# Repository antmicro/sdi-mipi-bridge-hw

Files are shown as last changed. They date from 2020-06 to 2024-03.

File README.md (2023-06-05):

# SDI to MIPI CSI-2 Bridge Hardware Design

Copyright (c) 2020-2023 [Antmicro](https://www.antmicro.com)

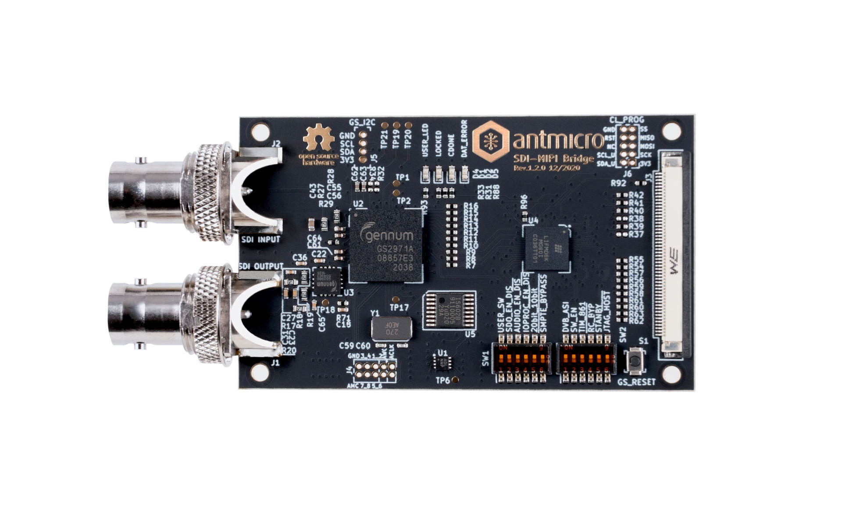
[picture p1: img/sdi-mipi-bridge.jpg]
SDI-MIPI Bridge


## Overview

This project contains open hardware KiCad design files for Antmicro's SDI to MIPI CSI-2 bridge.
This device enables connecting industrial and filmmaking cameras and video accessories to edge AI platforms which often include the MIPI CSI-2 interface.

The board includes an SDI input BNC connector and Antmicro's standard 50-pin FFC output connector (compatible with a range of our open hardware boards) exposing MIPI CSI-2 lanes as well as an I2C bus for configuration.

An additional SDI output (loopback) BNC connector is also available.

SDI signal conversion is implemented with a Semtech [GS2971A](https://www.semtech.com/products/broadcast-video/receivers-deserializers/gs2971a) deserializer which passes the parrallel 10-bit video data to the Lattice CrossLink [LIF-MD6000-6KMG80I](http://www.latticesemi.com/en/Products/FPGAandCPLD/CrossLink).
The CrossLink FPGA includes programmable logic and dedicated MIPI D-PHY transceivers.
It can be configured to accept parallel video data from the deserializer and transmit it over MIPI CSI-2 to the host platform.
SPI and I2C programming interfaces are exposed so the deserializer and the CrossLink FPGA can be configured from the host platform.

### Project structure

The main directory contains KiCad PCB project files, a LICENSE and README.
The remaining files are stored in the following directories:

* ``lib`` - contains the component libraries
* ``doc`` - contains board schematic in PDF
* ``img`` - contains graphics for this README

## Key Features

* Implements Single Link (3G-SDI) video conversion
* Supports SMPTE ST 425 (Level A and Level B), SMPTE ST 424, SMPTE ST 292, SMPTE ST 259-C and DVB-ASI as defined by the Semtec GS2971A specification
* Integrated loopback BNC connector for easy daisy-chaining with multiple SDI video accessories
* Audio de-embedder for 8 channels of 48kHz audio exposed on I2S 10 pin header
* Two 4-lane MIPI CSI-2 interfaces with up to 6 Gbps, each exposed on the 50 pin FFC connector.
* I2C configuration interface to handle CrossLink FPGA and SDI deserializer
* SPI interface for CrossLink configuration
* 12x DIP switches to initially configure the deserializer
* 2 LED indicators for user purposes

## Getting started

Please refer to the [SDI to MIPI CSI-2 bridge](https://github.com/antmicro/sdi-mipi-bridge) repository which aggregates the hardware design (this project), linux kernel sources, how-to documentation and reference HDL design for the CrossLink FPGA.

## License

This project is licensed under the [Apache-2.0](LICENSE) license.

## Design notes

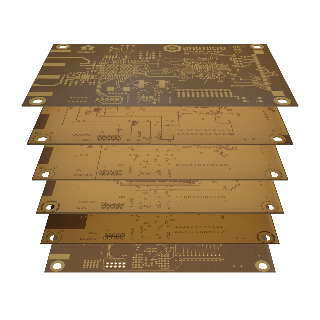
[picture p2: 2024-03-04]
assets/previews/layer1_thumbnail.webp

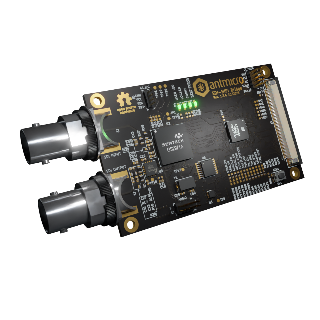
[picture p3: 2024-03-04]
assets/previews/leftT_thumbnail.png

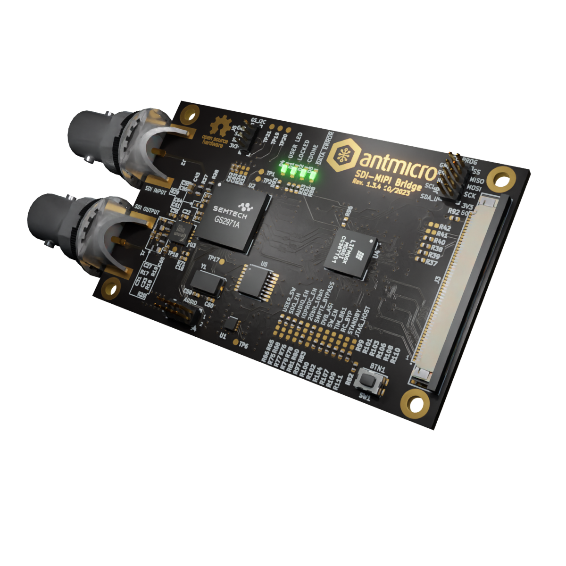
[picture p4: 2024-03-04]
assets/previews/rightT.webp

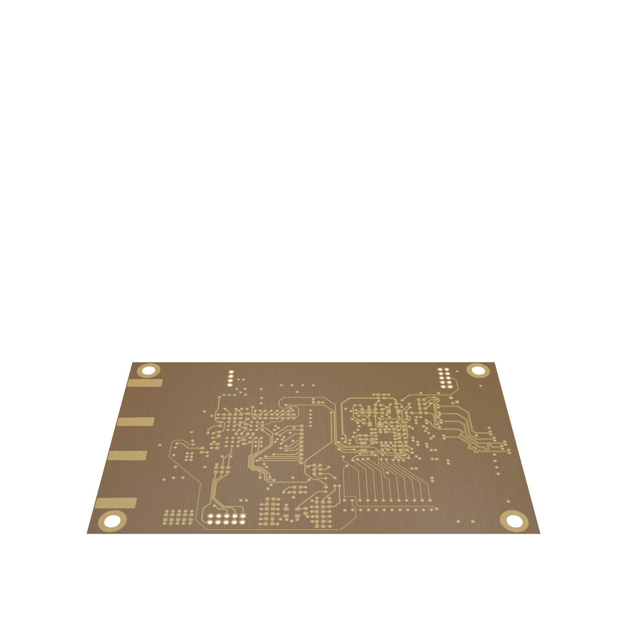
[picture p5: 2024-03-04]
assets/previews/layer6.png

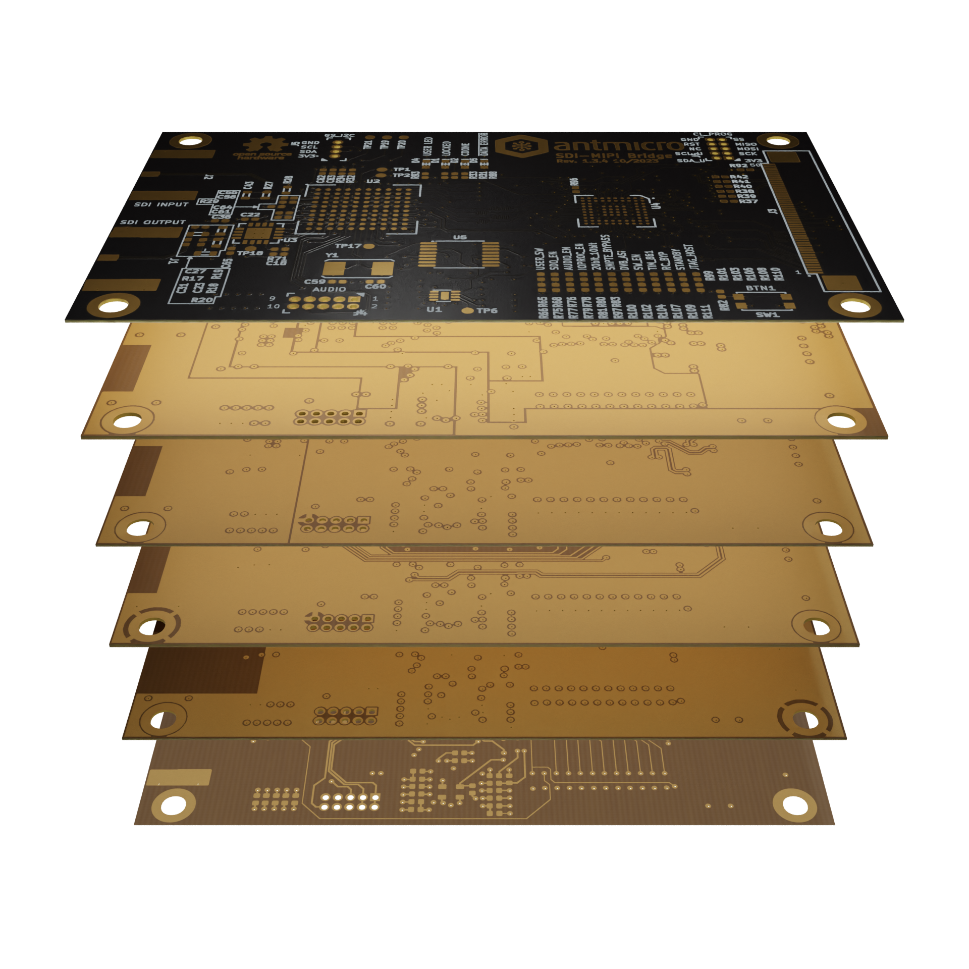
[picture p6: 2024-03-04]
assets/previews/stackup.png

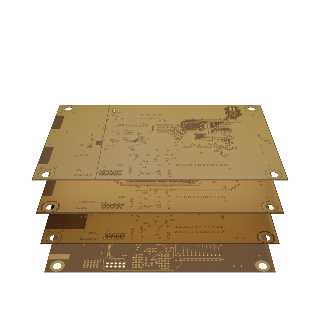
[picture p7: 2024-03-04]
assets/previews/layer3_thumbnail.webp

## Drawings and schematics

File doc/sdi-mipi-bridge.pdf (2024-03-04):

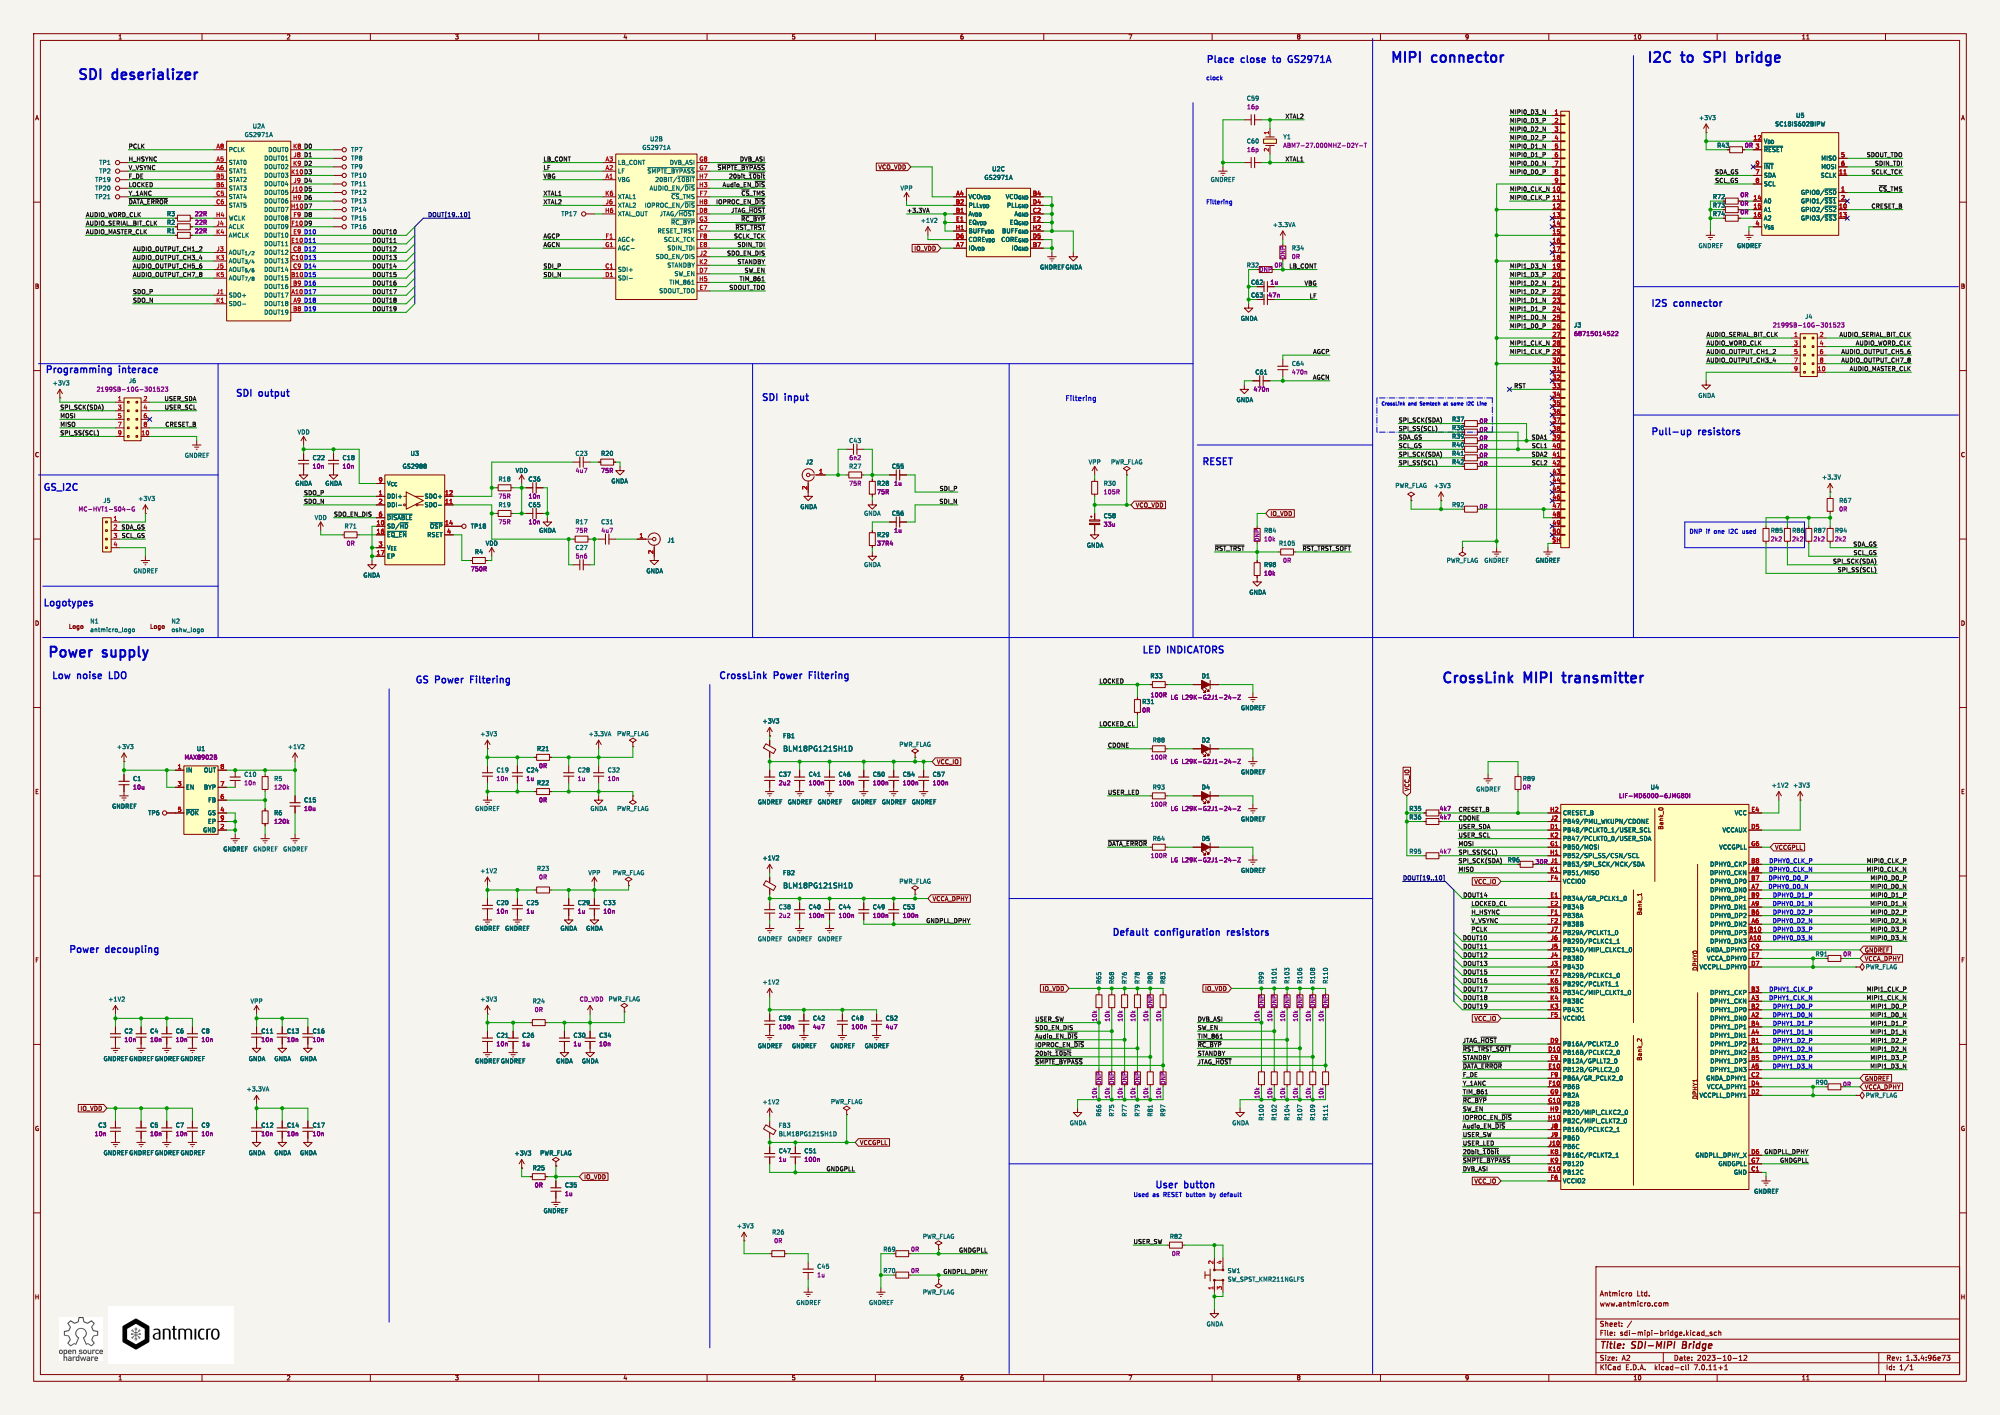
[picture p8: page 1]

clock GS Power Filtering

Used as RESET button by default

Antmicro Ltd.
File: sdi-mipi-bridge.kicad_sch Sheet: / www.antmicro.com

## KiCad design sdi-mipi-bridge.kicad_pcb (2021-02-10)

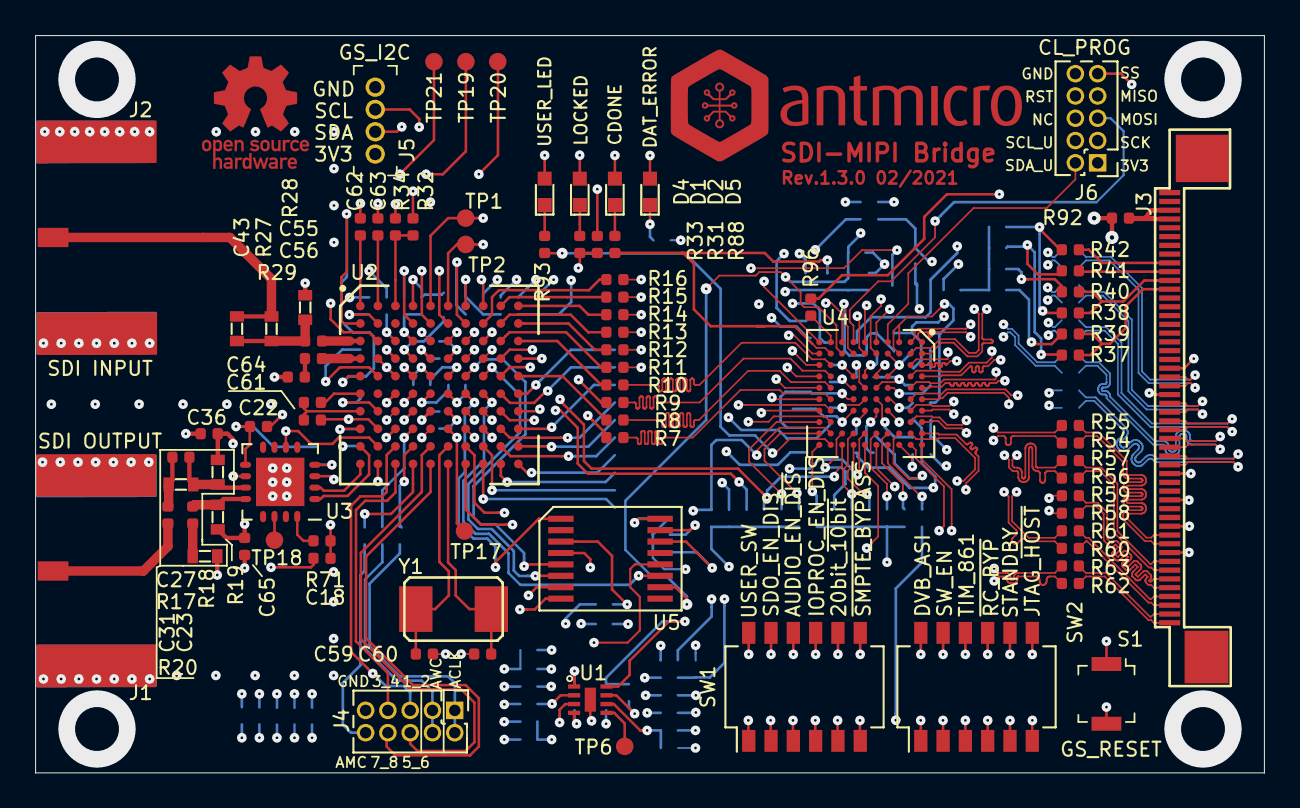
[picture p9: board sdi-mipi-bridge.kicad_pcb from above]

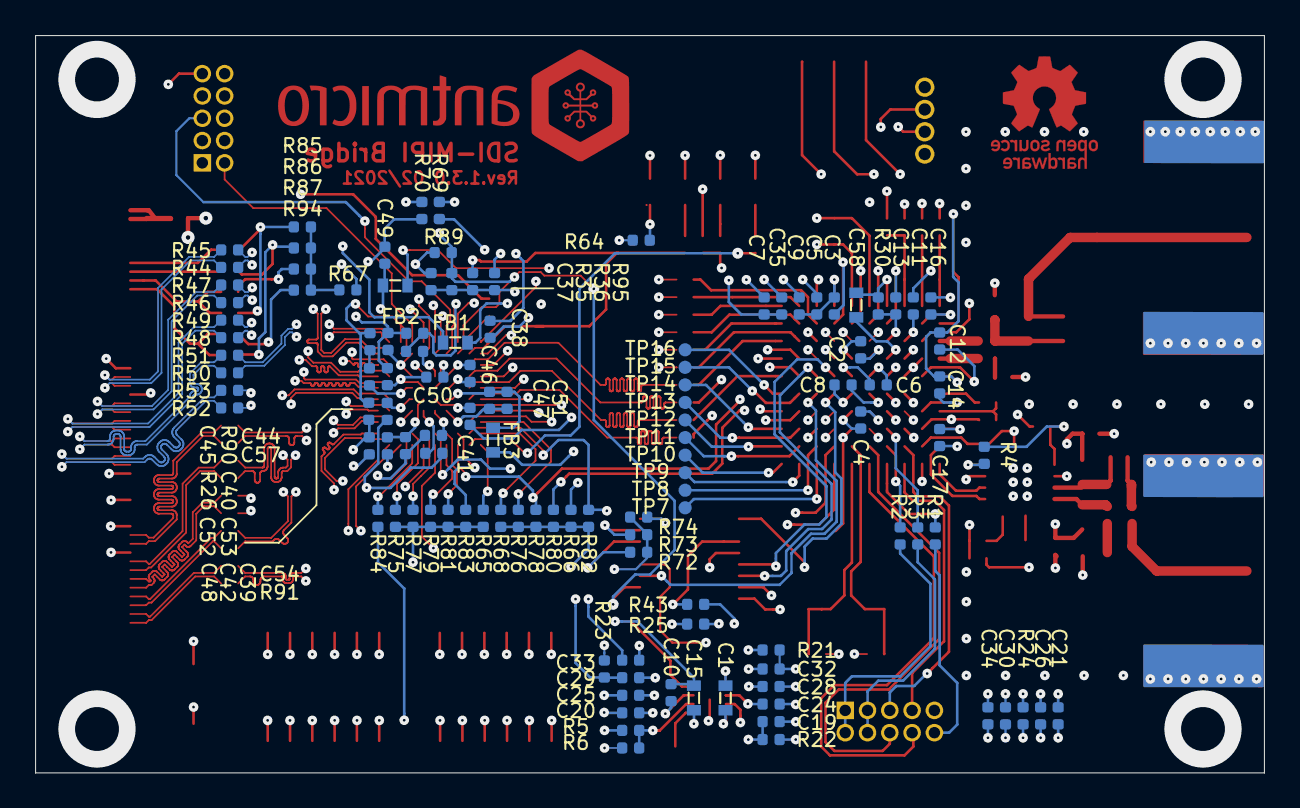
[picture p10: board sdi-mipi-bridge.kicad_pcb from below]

Board: 6 copper layers, 70.0 x 42.0 mm, 203 parts (116 on the bottom side), 174 nets.

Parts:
C1, C15: C_10u_0603; 0603-cap
C2, C3, C4, C5, C6, C7, C8, C9, C10, C11, C12, C13, C14, C16, C17, C18, C19, C20, C21, C22, C32, C33, C34, C36, C65: C_10n_0402; 0402-cap
C23, C31, C42, C52: C_4u7_0402; 0402-cap
C24, C25, C26, C28, C29, C30, C35, C45, C47, C55, C56, C62: C_1u_0402; 0402-cap
C27: C_5n6_0402; 0402-res
C37, C38: C_2u2_0402; 0402-cap
C39, C40, C41, C44, C46, C48, C49, C50, C51, C53, C54, C57: C_100n_0402_6V3; 0402-cap
C43: C_6n2_0603; 0603-res
C58: C_33u_0603; 0603-cap
C59, C60: C_16p_0402; 0402-res
C61, C64: C_470n_0402; 0402-cap
C63: C_47n_0402; 0402-cap
D1, D2, D4, D5: LG_L29K-G2J1-24-Z; LED_0603
FB1, FB2, FB3: BLM18PG121SH1D; 0603-res
J1, J2: 112740-13; BNC_Edge_Conn
J3: WE_68715014522_ONE-SIDE
J4, J6: GRPB052VWVN-RC; PinHeader_2x05_P1.27mm_Vertical
J5: GRPB041VWVN-RC; PinHeader_1x4_P1.27mm_Drill.7mm
N1: antmicro_logo; antmicro-logo_scaled_20mm
N2: oshw_logo; oshw-logo
R1, R2, R3: R_22R_0402; 0402-res
R4: R_750R_0402; 0402-res
R5, R6: R_120k_0402; 0402-res
R7, R8, R9, R10, R11, R12, R13, R14, R15, R16, R21, R22, R23, R24, R25, R26, R31, R32, R34, R37, R38, R39, R40, R41, R42, R43, R44, R45, R46, R47, R48, R49, R50, R51, R52, R53, R54, R55, R56, R57, R58, R59, R60, R61, R62, R63, R67, R69, R70, R71, R72, R73, R74, R89, R90, R91, R92: R_0R_0402; 0402-res
R17, R18, R19, R20, R27, R28: R_75R_0603; 0603-res
R29: R_37R4_0402; 0402-res
R30: R_105R_0402; 0402-res
R33, R64, R88, R93: R_100R_0402; 0402-res
R35, R36, R84, R95: R_4k7_0402; 0402-res
R65, R66, R68, R75, R76, R77, R78, R79, R80, R81, R82, R83: R_10k_0402; 0402-res
R85, R86, R87, R94: R_2k2_0402; 0402-res
R96: R_30R_0402; 0402-res
S1: B3U-1000P; Switch_Tactile_SMD_B3U-1000P
SW1, SW2: SW_DIP_x06; SW_SPST_6_Slide_MCDHN-06F-T-V_P1.27mm
TP1, TP2, TP6, TP17, TP18, TP19, TP20, TP21: TP_SMD1MM; Testpoint_smd_1mm
TP7, TP8, TP9, TP10, TP11, TP12, TP13, TP14, TP15, TP16: TP_SMD_0_75MM; Testpoint_smd_0_75mm
U1: MAX8902B; TDFN2x2
U2: GS2971A; BGA100_11x11mm
U3: GS2988; QFN-16_EP_4x4_Pitch0.65mm
U4: CrossLink_LIF-MD6000-6JMG80I; BGA-80pin_ckfBGA80_7.0x7.0mm
U5: SC18IS602BIPW; SC18IS602B
Y1: ABM7_27.000MH_D2Y_T; ABM7_OSC

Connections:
+1V2: C2.1, C4.1, C6.1, C8.1, C10.1, C15.1, C20.1, C25.1, C39.1, C42.1, C48.1, C52.1, FB2.1, FB3.1, R5.1, R23.1, U1.8, U2.D6, U2.E6, U2.F6, U2.G6, U4.E4, U4.E6
+3.3VA: C12.1, C14.1, C17.1, C28.1, C32.1, R21.2, R34.1, U2.B1, U2.E1, U2.H1
+3V3: C1.1, C19.1, C21.1, C24.1, C26.1, FB1.1, J5.1, J6.1, R21.1, R24.1, R25.1, R26.1, R43.1, R67.1, R92.2, U1.1, U1.3, U4.D5, U5.12
/20bit_~10bit~: R76.2, SW1.8, U2.H7, U4.K8
/AGCN: C61.1, C64.2, U2.G1
/AGCP: C64.1, U2.F1
/AUDIO_MASTER_CLK: J4.10, R1.1
/AUDIO_OUTPUT_CH1_2: J4.5, U2.J3
/AUDIO_OUTPUT_CH3_4: J4.7, U2.K3
/AUDIO_OUTPUT_CH5_6: J4.6, U2.J5
/AUDIO_OUTPUT_CH7_8: J4.8, U2.K5
/AUDIO_SERIAL_BIT_CLK: J4.1, J4.2, R2.1
/AUDIO_WORD_CLK: J4.3, J4.4, R3.1
/Audio_EN_~DIS~: R80.2, SW1.10, U2.H3, U4.J8
/CDONE: R36.1, R88.2, U4.J2
/CRESET_B: J6.8, R35.1, R89.2, U4.H2, U5.10
/D0: TP7.1, U2.K8
/D1: TP8.1, U2.J8
/D2: TP9.1, U2.K9
/D3: TP10.1, U2.K10
/D4: TP11.1, U2.J9
/D5: TP12.1, U2.J10
/D6: TP13.1, U2.H9
/D7: TP14.1, U2.H10
/D8: TP15.1, U2.F9
/D9: TP16.1, U2.F10
/D10: R7.2, U2.E9
/D11: R8.2, U2.E10
/D12: R9.2, U2.C8
/D13: R10.2, U2.C10
/D14: R11.2, U2.C9
/D15: R12.2, U2.B10
/D16: R13.2, U2.B9
/D17: R14.2, U2.A10
/D18: R15.2, U2.A9
/D19: R16.2, U2.B8
/DATA_ERRORb: R64.2, U2.C6, U4.E10
/DOUT10: R7.1, U4.J6
/DOUT11: R8.1, U4.J5
/DOUT12: R9.1, U4.J4
/DOUT13: R10.1, U4.J3
/DOUT14: R11.1, U4.E1
/DOUT15: R12.1, U4.K7
/DOUT16: R13.1, U4.K6
/DOUT17: R14.1, U4.K5
/DOUT18: R15.1, U4.K4
/DOUT19: R16.1, U4.K3
/DPHY0_CLK_N: R54.1, U4.A8
/DPHY0_CLK_P: R55.1, U4.B8
/DPHY0_D0_N: R56.1, U4.A7
/DPHY0_D0_P: R57.1, U4.B7
/DPHY0_D1_N: R58.1, U4.A9
/DPHY0_D1_P: R59.1, U4.B9
/DPHY0_D2_N: R60.1, U4.A6
/DPHY0_D2_P: R61.1, U4.B6
/DPHY0_D3_N: R62.1, U4.A10
/DPHY0_D3_P: R63.1, U4.B10
/DPHY1_CLK_N: R44.2, U4.A3
/DPHY1_CLK_P: R45.2, U4.B3
/DPHY1_D0_N: R46.2, U4.A2
/DPHY1_D0_P: R47.2, U4.B2
/DPHY1_D1_N: R48.2, U4.A4
/DPHY1_D1_P: R49.2, U4.B4
/DPHY1_D2_N: R50.2, U4.A1
/DPHY1_D2_P: R51.2, U4.B1
/DPHY1_D3_N: R52.2, U4.A5
/DPHY1_D3_P: R53.2, U4.B5
/DVB_ASI: R65.1, SW2.12, U2.G8, U4.K10
/F_DE: TP19.1, U2.B5, U4.F9
/GNDGPLL: C47.2, C51.2, R69.2, U4.G7
/GNDPLL_DPHY: C49.2, C53.2, R70.2, U4.D6
/H_HSYNC: TP1.1, U2.A5, U4.F1
/IOPROC_EN_~DIS~: R78.2, SW1.9, U2.H8, U4.H10
/JTAG_~HOST~: R75.1, SW2.7, U2.D8, U4.D9
/LB_CONT: R32.2, R34.2, U2.A3
/LF: C63.2, U2.A2
/LOCKED: R31.1, R33.2, TP20.1, U2.B6
/LOCKED_CL: R31.2, U4.E2
/MIPI0_CLK_N: J3.10, R54.2
/MIPI0_CLK_P: J3.11, R55.2
/MIPI0_D0_N: J3.7, R56.2
/MIPI0_D0_P: J3.8, R57.2
/MIPI0_D1_N: J3.5, R58.2
/MIPI0_D1_P: J3.6, R59.2
/MIPI0_D2_N: J3.3, R60.2
/MIPI0_D2_P: J3.4, R61.2
/MIPI0_D3_N: J3.1, R62.2
/MIPI0_D3_P: J3.2, R63.2
/MIPI1_CLK_N: J3.28, R44.1
/MIPI1_CLK_P: J3.29, R45.1
/MIPI1_D0_N: J3.25, R46.1
/MIPI1_D0_P: J3.26, R47.1
/MIPI1_D1_N: J3.23, R48.1
/MIPI1_D1_P: J3.24, R49.1
/MIPI1_D2_N: J3.21, R50.1
/MIPI1_D2_P: J3.22, R51.1
/MIPI1_D3_N: J3.19, R52.1
/MIPI1_D3_P: J3.20, R53.1
/MISO: J6.7, U4.K1
/MOSI: J6.5, U4.G1
/PCLK: U2.A8, U4.J7
/RST_TRST: R84.2, S1.1, U2.C7, U4.D10
/SCL1: J3.40, R38.1, R40.1
/SCL2: J3.42, R42.1
/SCLK_TCK: U2.F8, U5.11
/SCL_GS: J5.3, R40.2, R87.2, U5.8
/SDA1: J3.39, R37.1, R39.1
/SDA2: J3.41, R41.1
/SDA_GS: J5.2, R39.2, R94.2, U5.7
/SDIN_TDI: U2.E8, U5.6
/SDI_N: C56.1, U2.D1
/SDI_P: C55.1, U2.C1
/SDOUT_TDO: U2.E7, U5.5
/SDO_EN_DIS: R66.2, SW1.11, U2.J2, U3.6
/SDO_N: U2.K1, U3.2
/SDO_P: U2.J1, U3.1
/SPI_SCK(SDA): J6.3, R37.2, R41.2, R86.2, R96.1
/SPI_SS(SCL): J6.9, R38.2, R42.2, R85.2, R95.1, U4.H1
/STANDBY: R77.1, SW2.8, U2.K2, U4.E9
/SW_EN: R83.1, SW2.11, U2.D7, U4.H9
/TIM_861: R81.1, SW2.10, U2.H5, U4.G9
/USER_LED: R93.2, U4.J10
/USER_SCL: J6.4, U4.K2
/USER_SDA: J6.2, U4.D1
/USER_SW: R82.2, SW1.12, U4.J9
/VBG: C62.2, U2.A1
/V_VSYNC: TP2.1, U2.A6, U4.F2
/XTAL1: C60.1, U2.K6, Y1.2
/XTAL2: C59.1, U2.J6, Y1.1
/Y_1ANC: TP21.1, U2.C5, U4.F10
/~CS~_TMS: U2.F7, U5.1
/~RC_BYP~: R79.1, SW2.9, U2.G3, U4.G10
/~SMPTE_BYPASS~: R68.2, SW1.7, U2.G7, U4.K9
GNDA: C11.2, C12.2, C13.2, C14.2, C16.2, C17.2, C18.2, C22.2, C28.2, C29.2, C30.2, C32.2, C33.2, C34.2, C36.1, C58.2, C61.2, C62.1, C63.1, C65.1, J1.1, J2.1, J4.9, R20.1, R22.2, R28.2, R29.2, R32.1, R65.2, R66.1, R68.1, R75.2, R76.1, R77.2, R78.1, R79.2, R80.1, R81.2, R82.1, R83.2, S1.2, U2.B4, U2.C2, U2.D2, U2.D3, U2.D4, U2.E2, U2.E3, U2.E4, U2.F3, U2.F4, U2.G2, U2.H2, U3.3, U3.10, U3.17
GNDREF: C1.2, C2.2, C3.2, C4.2, C5.2, C6.2, C7.2, C8.2, C9.2, C15.2, C19.2, C20.2, C21.2, C24.2, C25.2, C26.2, C35.2, C37.2, C38.2, C39.2, C40.2, C41.2, C42.2, C44.2, C45.2, C46.2, C48.2, C50.2, C52.2, C54.2, C57.2, C59.2, C60.2, D1.2, D2.2, D4.2, D5.2, J3.9, J3.12, J3.15, J3.18, J3.27, J3.30, J5.4, J6.10, R6.2, R22.1, R69.1, R70.1, R72.1, R73.1, R74.1, R89.1, U1.2, U1.4, U1.~, U2.B7, U2.D5, U2.D9, U2.E5, U2.F5, U2.G4, U2.G5, U2.G9, U2.J7, U4.C1, U4.C2, U4.C9, U4.C10, U4.E5, U4.G2, U4.G5, U5.4
IO_VDD: C3.1, C5.1, C7.1, C9.1, C35.1, R25.2, R84.1, SW1.1, SW1.2, SW1.3, SW1.4, SW1.5, SW1.6, SW2.1, SW2.2, SW2.3, SW2.4, SW2.5, SW2.6, U2.A7, U2.D10, U2.G10, U2.K7
unnamed: C10.2, U1.7
unnamed: C23.1, R19.1, U3.12
unnamed: C23.2, R20.2
unnamed: C27.1, C31.2, R17.2
unnamed: C27.2, R17.1, R18.1, U3.11
unnamed: C31.1, J1.2
unnamed: C43.1, C55.2, R27.1, R28.1
unnamed: C43.2, J2.2, R27.2
unnamed: C45.1, R26.2
unnamed: C56.2, R29.1
unnamed: D1.1, R33.1
unnamed: D2.1, R88.1
unnamed: D4.1, R93.1
unnamed: D5.1, R64.1
unnamed: J3.47, J3.48, R92.1
unnamed: R1.2, U2.K4
unnamed: R2.2, U2.J4
unnamed: R3.2, U2.H4
unnamed: R4.2, U3.4
unnamed: R5.2, R6.1, U1.6
unnamed: R43.2, U5.3
unnamed: R67.2, R85.1, R86.1, R87.1, R94.1
unnamed: R71.2, U3.16
unnamed: R72.2, U5.14
unnamed: R73.2, U5.15
unnamed: R74.2, U5.16
unnamed: R90.2, U4.D2, U4.D4
unnamed: R91.2, U4.D7, U4.E7
unnamed: R96.2, U4.J1
unnamed: TP6.1, U1.5
unnamed: TP17.1, U2.H6
unnamed: TP18.1, U3.14
VCCA_DPHY: C38.1, C40.1, C44.1, C49.1, C53.1, FB2.2, R90.1, R91.1
VCCGPLL: C47.1, C51.1, FB3.2, U4.G6
VCC_IO: C37.1, C41.1, C46.1, C50.1, C54.1, C57.1, FB1.2, R35.2, R36.2, R95.2, U4.F4, U4.F5, U4.F6, U4.F7, U4.G4
VCO_VDD: C58.1, R30.2, U2.A4
VDD: C18.1, C22.1, C30.1, C34.1, C36.2, C65.2, R4.1, R18.2, R19.2, R24.2, R71.1, U3.9
VPP: C11.1, C13.1, C16.1, C29.1, C33.1, R23.2, R30.1, U2.B2, U2.C3, U2.C4

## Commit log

2019-11-18 Add schematic sheet
    [PowerSupplies.sch, SDI-bridge.kicad_pcb, SDI-bridge.sch]
2019-11-18 Add descriptions
    [PowerSupplies.sch, SDI-bridge.sch]
2020-06-25 Update directory structure
    [PowerSupplies.sch, SDI-bridge.kicad_pcb, SDI-bridge.sch]
2020-06-25 Add todos
    [PowerSupplies.sch, SDI-bridge.sch]
2020-06-25 Add updated schematic
    [SDI-bridge.sch]
2020-06-25 Arrange pcb components and add jumpers and logo
    [SDI-bridge.kicad_pcb, SDI-bridge.sch]
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2020-06-25 Add routing - WIP
    [SDI-bridge.kicad_pcb, SDI-bridge.sch]
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2020-06-25 Add CrossLink to schematic
    Also changed:
    -add 50-pin mipi connector
    -remove b2b connector
    -remove jumpers and conect signals to fpga
    -remove audio testpats and connect signals to fpga
    [SDI-bridge.sch]
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2020-06-25 Add CrossLink power filtering
    [SDI-bridge.sch]
2020-06-25 Initial component placement and outline definition
    [SDI-bridge.kicad_pcb, SDI-bridge.sch]
2020-06-25 Expose DPHY1 at FFC connector
    [SDI-bridge.kicad_pcb, SDI-bridge.sch]
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2020-06-25 Schematic changes after design review
    [SDI-bridge.kicad_pcb, SDI-bridge.sch]
2020-06-25 Add routing on 6 layers
    [SDI-bridge.kicad_pcb, SDI-bridge.sch]
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2020-06-25 Fix inner layer clearance and tracks width
    [SDI-bridge-B_Cu.gbr, SDI-bridge-B_Mask.gbr, SDI-bridge-B_Paste.gbr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]
2020-06-25 Add I2S connector and GND planes
    [SDI-bridge.kicad_pcb, SDI-bridge.sch]
2020-06-25 Fix inner layer clearance
    [SDI-bridge-B_Cu.gbr, SDI-bridge-B_Mask.gbr, SDI-bridge-B_Paste.gbr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]
2020-06-25 Remove stub at F2
    [SDI-bridge-B_Cu.gbr, SDI-bridge-B_Mask.gbr, SDI-bridge-B_Paste.gbr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]
2020-06-25 Minor fixes added to layout
    [SDI-bridge.kicad_pcb]
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2020-06-25 Add LED indicators and swap pin numbers of BNC connectors
    [SDI-bridge.sch]
2020-06-25 Tune differential pair lengths
    [SDI-bridge.kicad_pcb]
2020-06-25 Rework the layout of SDI input and output path
    [SDI-bridge.kicad_pcb, SDI-bridge.sch]
2020-06-25 Fixed designators orientation
    [SDI-bridge.kicad_pcb]
2020-06-25 Switch In1.Cu with In4.Cu and add via fence
    [SDI-bridge.kicad_pcb]
2020-06-25 Tune parallel signal length
    [SDI-bridge.kicad_pcb]
2020-06-25 Add several components to simplify the debugging process
    -Add DIP switches for GS external configuration
    -Make PCB a bit widther
    -Move monting holes to the board sides
    -Move power supply components
    -Add Programming connectors
    -Expose all audio pins at header
    -Add GS reset button
    -Add 2x user led and data error led
    [SDI-bridge.kicad_pcb, SDI-bridge.sch]
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2020-06-25 Update revision info on PCB
    [SDI-bridge.kicad_pcb]
2020-06-25 Fix minor footprint bug
    [SDI-bridge.kicad_pcb]
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2020-06-25 Add OSHW logo and fix CS pin
    There are following changes made:
    -Disconnect CS pin from dip switch
    -Replace one user led with user switch
    -Remove leftovers form previous revision
    -Update date and revision
    [SDI-bridge.kicad_pcb, SDI-bridge.sch]
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2020-07-02 Fixed 3V3 reference
    [sdi-mipi-bridge.sch]
2020-07-02 Added missing MPNs
    [sdi-mipi-bridge.kicad_pcb, sdi-mipi-bridge.sch]
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2020-08-19 Add stackup table to the PCB fab layer
    [sdi-mipi-bridge.kicad_pcb]
2020-08-20 Update 3D model of the BNC connector
    [sdi-mipi-bridge.kicad_pcb]
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2020-11-29 Changed MFG and MPN for some parts to ease sourcing
    [sdi-mipi-bridge.sch]
2020-11-29 Chnage from 12G to 6G BNC connectors
    [sdi-mipi-bridge.sch]
2020-11-30 Change C37 from 2n2 to 2u2
    [sdi-mipi-bridge.kicad_pcb, sdi-mipi-bridge.sch]
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2020-12-03 Connect PCLK to J7 pin
    [sdi-mipi-bridge.sch]
2020-12-03 Replace DOUT10 and DOUT11 resistors with test pads
    [sdi-mipi-bridge.sch]
2020-12-03 Add DNP field to SDA_CL resistors
    [sdi-mipi-bridge.sch]
2020-12-03 Add second user LED
    [sdi-mipi-bridge.sch]
2020-12-03 Add changes to PCB
    Connect PCLK signal to J7 pin of FPGA
    Replace DOUT10 and DOUT11 resistors with test pads
    Add second user LED indicator
    [sdi-mipi-bridge.kicad_pcb]
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2020-12-04 Change data pins connection
    [sdi-mipi-bridge.sch]
2020-12-04 Change data pins routing
    [sdi-mipi-bridge.kicad_pcb]
2020-12-04 Minor fix, regenerate schematics
    [sdi-mipi-bridge.sch]
2020-12-04 Re-mapped Dx signal names between the deserializer and CrossLink
    [sdi-mipi-bridge.sch]
2020-12-04 Update PCB, DRC clean
    [sdi-mipi-bridge.kicad_pcb]
2020-12-16 Add 0R resistor on 3.3v input to allow FFC to be disconnected from net
    [sdi-mipi-bridge.kicad_pcb, sdi-mipi-bridge.sch]
2020-12-18 Increase 3.3v trace width, added 2nd via, increased via diameter
    [sdi-mipi-bridge.kicad_pcb]
2020-12-18 Change font size for R92
    [sdi-mipi-bridge.kicad_pcb]
2020-12-18 Change RST pullup from 2k2 to 4k7 and note I2C pull-ups as DNP
    [sdi-mipi-bridge.kicad_pcb, sdi-mipi-bridge.sch]
2021-02-10 Bump release to 1.3.0
    [sdi-mipi-bridge.kicad_pcb, sdi-mipi-bridge.sch]
2021-02-10 Connect CRESET_B to GPIO2 from U5
    [sdi-mipi-bridge.sch]
2021-02-10 Connect configuration I2C from U4 to J3
    [sdi-mipi-bridge.sch]
2021-02-10 Reuse R37,R38 to reconnect configuration I2C
    [sdi-mipi-bridge.sch]
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2021-02-10 Update STANDBY label near SW2
    [sdi-mipi-bridge.kicad_pcb]
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2021-04-13 Update sw_setup.rst
    `make modules_install` fails due to permission issues in the unpacked rootfs.
    If run with sudo, the current kernel config is ignored and a prompt is entered. Additional steps have been added to change the lib/modules and lib/firmware directories to be owned by the current user prior to the module_install command, then ownership is reverted back to the root user.
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2023-02-27 Ported to KiCAD 6
    [sdi-mipi-bridge.kicad_pcb, sdi-mipi-bridge.kicad_sch, sdi-mipi-bridge.sch]
2023-02-27 Tidy up the schematic
    [sdi-mipi-bridge.kicad_sch]
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2023-02-27 Fixed DIP switches shorting FPGA to IO_VDD
    [sdi-mipi-bridge.kicad_sch]
2023-03-01 Removed DIP switches and improved RST_TRST circuitry
    [sdi-mipi-bridge.kicad_sch]
2023-03-01 Ported DIP switch and reset changes to the PCB
    [sdi-mipi-bridge.kicad_sch]
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2023-03-01 Unified configuration naming and changed DATA_ERROR name polarity
    [sdi-mipi-bridge.kicad_sch]
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2023-06-12 Remove 0R resistors from the fast signal lanes
    [sdi-mipi-bridge.kicad_sch]
2023-06-13 Bump project revision to 1.3.1
    [sdi-mipi-bridge.kicad_sch]
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2023-06-13 Resolve DRC issues related to silkscreen
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2023-07-17 Standardized SDI input and output sections
    [sdi-mipi-bridge.kicad_sch]
2023-07-17 Started standardizing the schematic
    [sdi-mipi-bridge.kicad_sch]
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2023-07-18 Started migrating the PCB
    [sdi-mipi-bridge.kicad_sch]
2023-07-19 Imported schematic changes to the PCB and placed components
    [sdi-mipi-bridge.kicad_sch]
2023-07-19 Finished migrating the PCB silkscreen
    [sdi-mipi-bridge.kicad_sch]
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2023-07-26 Added missing layers in PCB stackup
2023-08-09 [#47298] Bump revision to 1.3.2
    [sdi-mipi-bridge.kicad_sch]
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2023-08-09 [#47298] Fix most of the ERC errors
    [sdi-mipi-bridge.kicad_sch]
2023-08-09 [#47298] Fix MAX8902B symbol
    Change pin 8 type from output to power output
2023-08-09 [#47298] Fix ERC errors
    [sdi-mipi-bridge.kicad_sch]
2023-08-09 [#47298] Add ERC exclusion to power symbols
    [sdi-mipi-bridge.kicad_sch]
2023-08-09 [#47298] Fix ERC
    [sdi-mipi-bridge.kicad_sch]
2023-08-09 [#47298] Fix DNP
    [sdi-mipi-bridge.kicad_sch]
2023-08-09 [#47298] Resolve ERC errors. ERC clean. DRC clean
    [sdi-mipi-bridge.kicad_sch]
2023-08-09 [#47298] Bump revision to 1.3.3
    [sdi-mipi-bridge.kicad_sch]
2023-08-22 [#48149] Change GS297 footprint for footprint with markings
    [sdi-mipi-bridge.kicad_sch]
2023-08-23 [#48149] Update GS297 symbol, update loclib
    [sdi-mipi-bridge.kicad_sch]
2023-09-11 Update default configuration resistors
    [sdi-mipi-bridge.kicad_sch]
2023-09-11 Bump revision to 1.3.4
    [sdi-mipi-bridge.kicad_sch]
2023-10-12 50070 fix drc
    [sdi-mipi-bridge.kicad_sch]
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2024-02-26 [#55723] Fix 2199SB-10G-301523
    [sdi-mipi-bridge.kicad_sch]
2024-02-26 [#55723] Fix MC-HVT1-S04-G
    [sdi-mipi-bridge.kicad_sch]
2024-02-26 [#55723] Fix MAX8902B
    [sdi-mipi-bridge.kicad_sch]
2024-02-26 [#55723] Fix LIF-MD6000-6JMG80I
    [sdi-mipi-bridge.kicad_sch]
2024-02-26 [#55723] Updated fixed components on pcb
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2024-02-29 [#55723] Fix Conn_BNC_031-70526-21
    [sdi-mipi-bridge.kicad_sch]
2024-04-02 Fix symbols/footprint coordinates
    [sdi-mipi-bridge.kicad_sch]
